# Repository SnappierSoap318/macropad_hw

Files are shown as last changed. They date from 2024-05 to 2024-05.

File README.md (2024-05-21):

# macropad_hw
Hardware for macropad

# Bom
|#  |Reference |Qty|Value |Footprint |DNP|
|---|---|---|---|---|---|
|1  |BT1 |1  |Battery_Cell|Battery:BatteryHolder_MPD_BH-18650-PC2 | |
|2  |C1 |1  |1uF |Capacitor_THT:C_Disc_D4.3mm_W1.9mm_P5.00mm | |
|3  |C2 |1  |0.1uF |Capacitor_THT:C_Disc_D4.3mm_W1.9mm_P5.00mm | |
|4  |D1, D2, D3, D4, D5, D6, D7, D8, D9, D10, D11, D12, D13, D14, D15, D16 |16 |LED |Diode_SMD:D_1206_3216Metric | |
|5  |H1, H2, H3, H4, H5, H6, H7, H8 |8  |MountingHole|MountingHole:MountingHole_2.5mm | |
|6  |SW1 |1  |SW_SPST |Button_Switch_THT:SW_CuK_JS202011CQN_DPDT_Straight| |
|7  |U1 |1  |CD74HC4067M |Package_SO:SOIC-24W_7.5x15.4mm_P1.27mm | |
|8  |U2, U3, U4, U5, U6, U7, U8, U9, U10, U11, U12, U13, U14, U15, U16, U17|16 |~ |Gateron:Gatreon KS-20 | |
|9  |U18 |1  |~ |Nice!nano | |

this is aimed a wireless Analog macropad, any suggestions and changes are welcome.

PS, ik there isnt any holes to move the switches, have to add that in the next revision of the dxf files maybe.

PS:2, The code for running this is [here](https://github.com/SnappierSoap318/macropad)

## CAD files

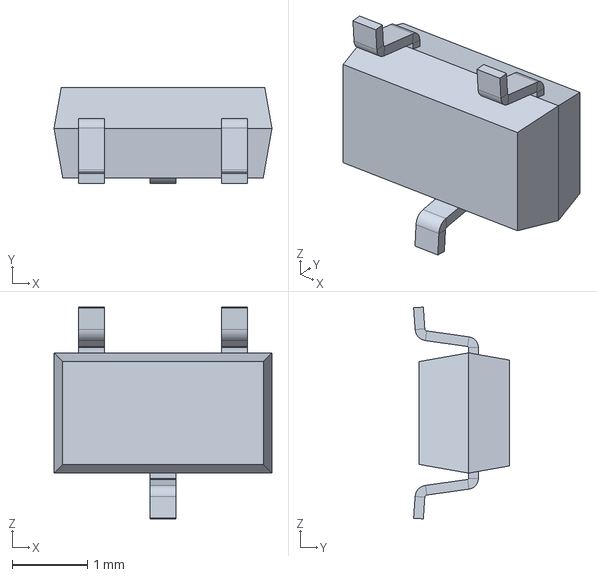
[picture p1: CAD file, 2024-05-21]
3d/sps-siot-magnetic-sensor-ic-cad-rendering-sot-23-ciid-150231.stp
2.90 x 1.27 x 2.82 mm

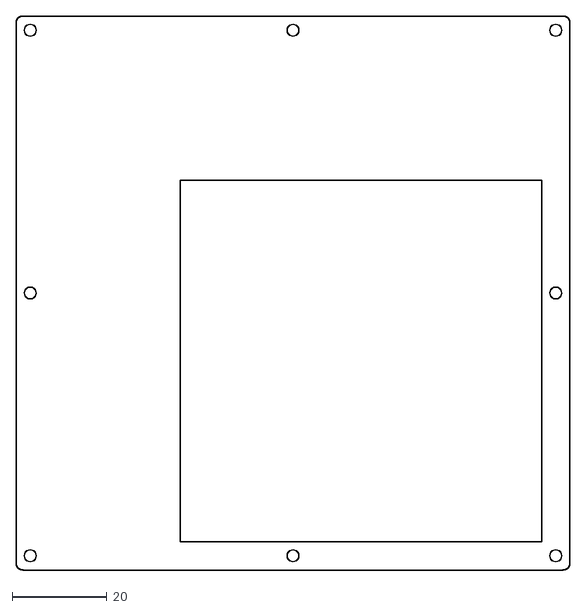
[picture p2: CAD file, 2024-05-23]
Laser Cut/top.dxf
116.8 x 116.8

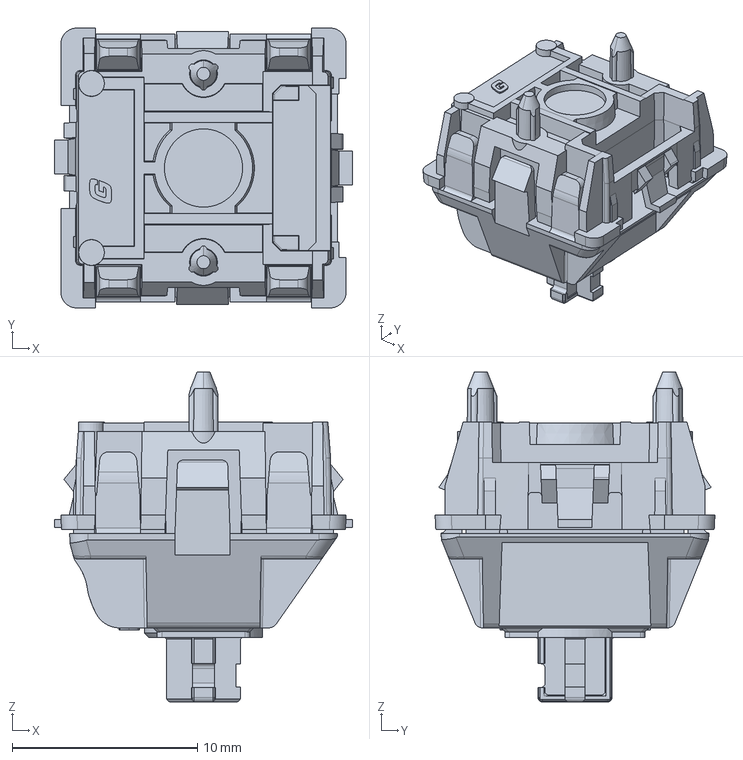
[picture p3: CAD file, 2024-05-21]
3d/Gateron KS-20 Magnetic Hall Sensor Switch KS-20T-20210922.stp
16.1 x 15.1 x 17.8 mm

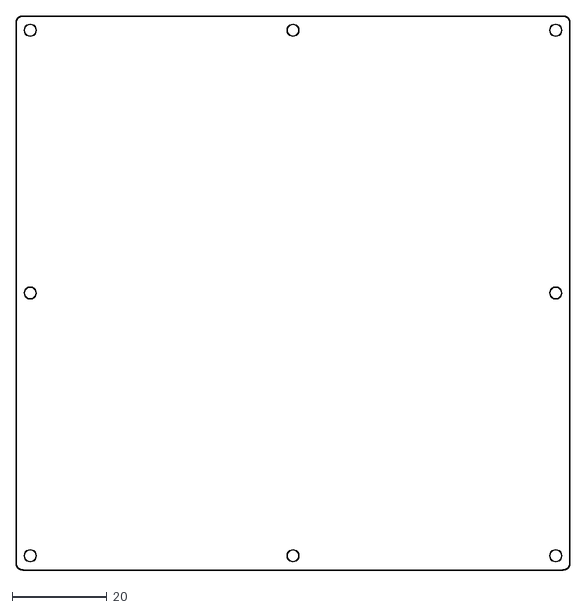
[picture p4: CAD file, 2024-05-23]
Laser Cut/bottom.dxf
116.8 x 116.8

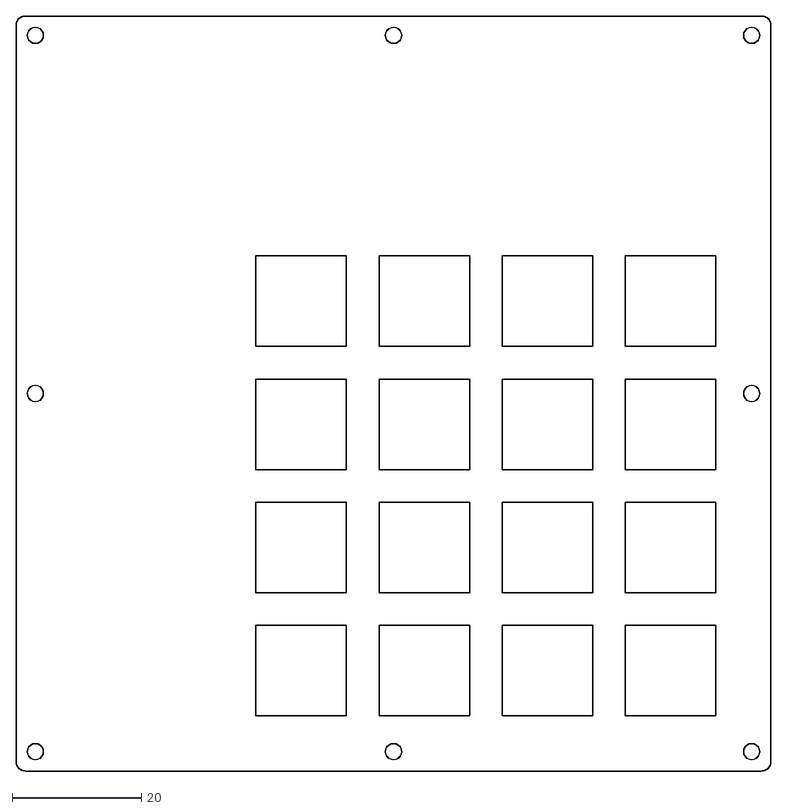
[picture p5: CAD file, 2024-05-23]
Laser Cut/switch.dxf
116.8 x 116.8

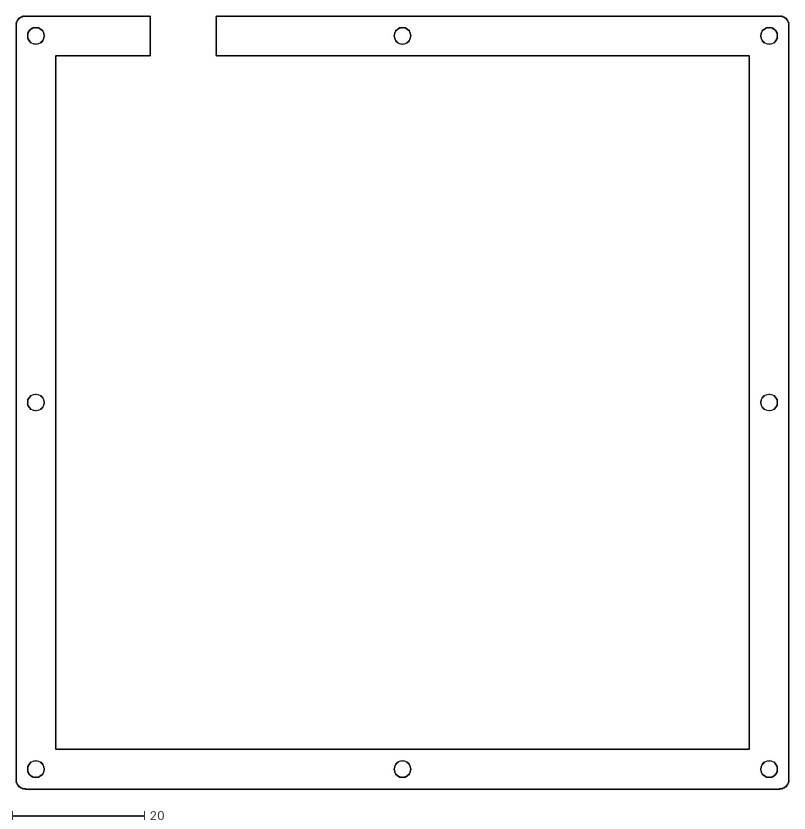
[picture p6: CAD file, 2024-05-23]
Laser Cut/open.dxf
116.8 x 116.8

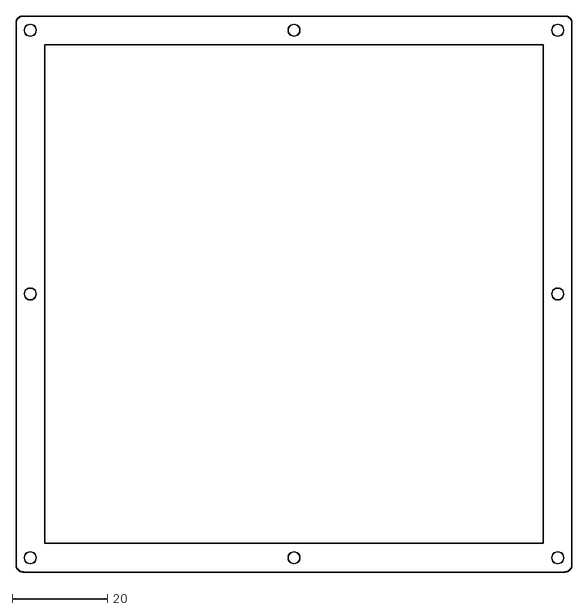
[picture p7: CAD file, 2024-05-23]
Laser Cut/closed.dxf
116.8 x 116.8

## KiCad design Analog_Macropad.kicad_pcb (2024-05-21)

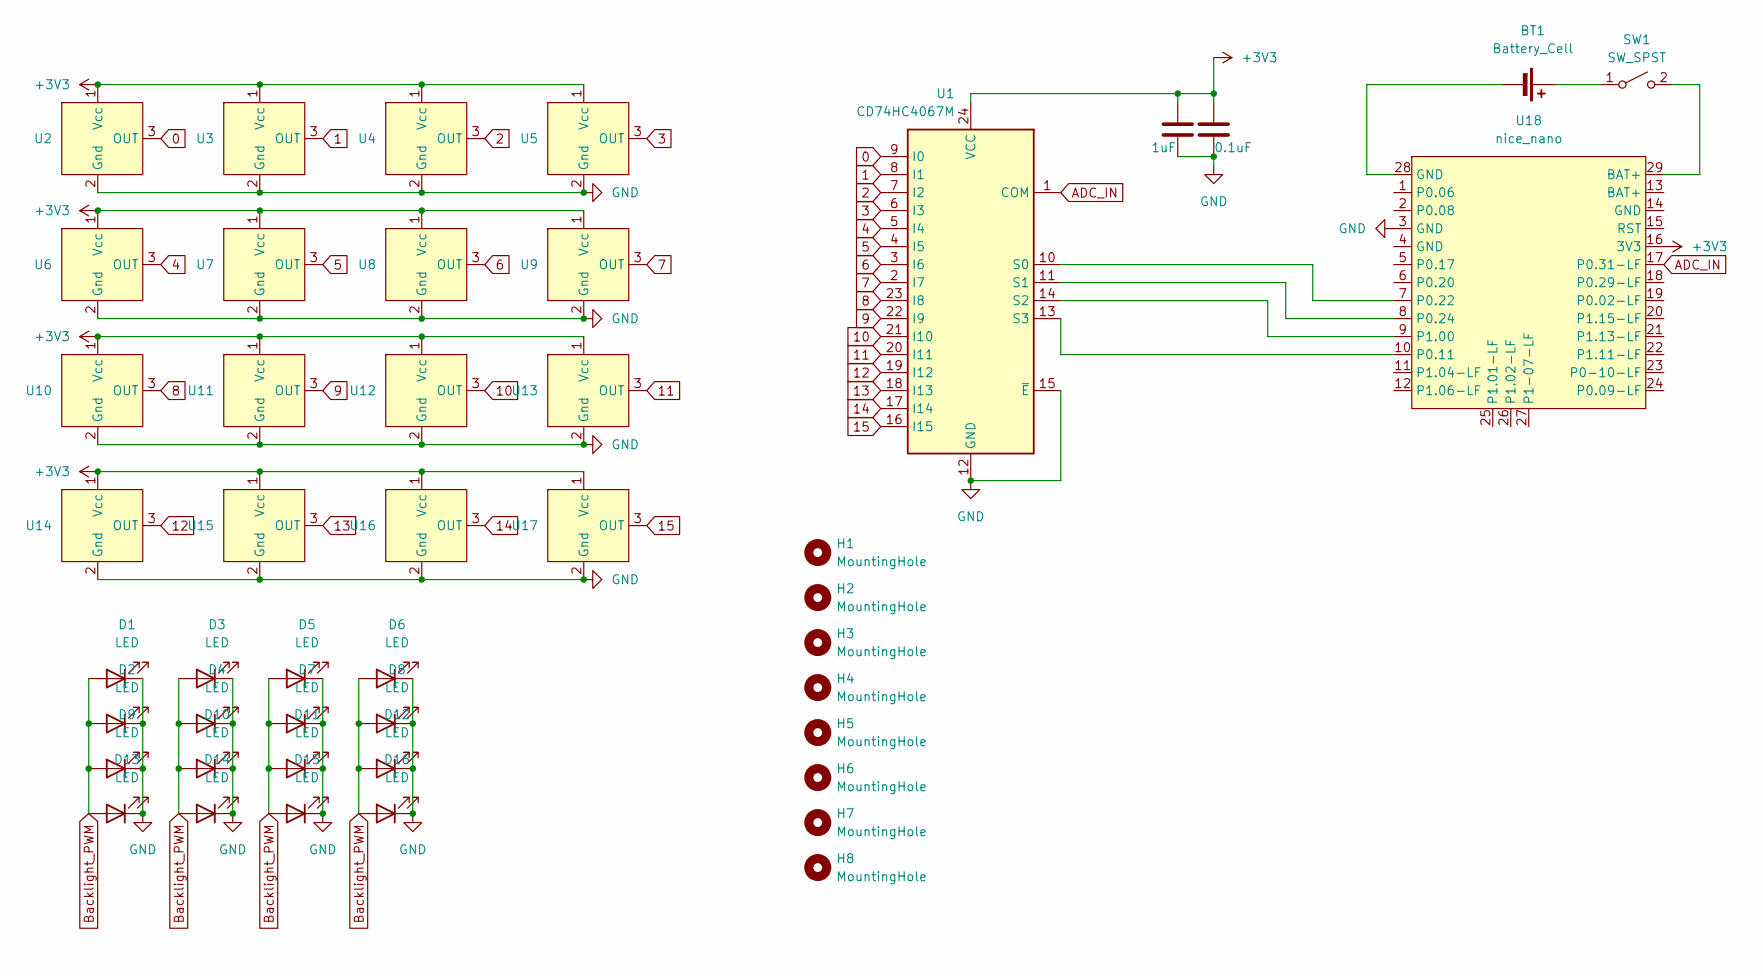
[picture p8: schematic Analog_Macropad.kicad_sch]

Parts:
BT1: Battery_Cell; BatteryHolder_MPD_BH-18650-PC2
C3: 1uF; C_Disc_D4.3mm_W1.9mm_P5.00mm
C4: 0.1uF; C_Disc_D4.3mm_W1.9mm_P5.00mm
D1, D2, D3, D4, D5, D6, D7, D8, D9, D10, D11, D12, D13, D14, D15, D16: LED; D_1206_3216Metric
H1, H2, H3, H4, H5, H6, H7, H8: MountingHole; MountingHole_2.5mm
SW1: SW_SPST; SW_CuK_JS202011CQN_DPDT_Straight
U1: CD74HC4067M; SOIC-24W_7.5x15.4mm_P1.27mm
U2, U3, U4, U5, U6, U7, U8, U9, U10, U11, U12, U13, U14, U15, U16, U17: Gatreon KS-20
U18: nice_nano; nice_nano_AH_USBup

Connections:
0: U1.9 (I0), U2.3 (OUT)
1: U1.8 (I1), U3.3 (OUT)
2: U1.7 (I2), U4.3 (OUT)
3: U1.6 (I3), U5.3 (OUT)
4: U1.5 (I4), U6.3 (OUT)
5: U1.4 (I5), U7.3 (OUT)
6: U1.3 (I6), U8.3 (OUT)
7: U1.2 (I7), U9.3 (OUT)
8: U1.23 (I8), U10.3 (OUT)
9: U1.22 (I9), U11.3 (OUT)
10: U1.21 (I10), U12.3 (OUT)
11: U1.20 (I11), U13.3 (OUT)
12: U1.19 (I12), U14.3 (OUT)
13: U1.18 (I13), U15.3 (OUT)
14: U1.17 (I14), U16.3 (OUT)
15: U1.16 (I15), U17.3 (OUT)
+3V3: U1.24 (VCC), U2.1 (Vcc), U3.1 (Vcc), U4.1 (Vcc), U5.1 (Vcc), U6.1 (Vcc), U7.1 (Vcc), U8.1 (Vcc), U9.1 (Vcc), U10.1 (Vcc), U11.1 (Vcc), U12.1 (Vcc), U13.1 (Vcc), U14.1 (Vcc), U15.1 (Vcc), U16.1 (Vcc), U17.1 (Vcc), U18.16 (3V3); also elsewhere on the board
ADC_IN: U1.1 (COM), U18.17 (P0.31-LF)
Backlight_PWM: D1.2 (A), D2.2 (A), D3.2 (A), D4.2 (A), D5.2 (A), D6.2 (A), D7.2 (A), D8.2 (A), D9.2 (A), D10.2 (A), D11.2 (A), D12.2 (A), D13.2 (A), D14.2 (A), D15.2 (A), D16.2 (A)
GND: D1.1 (K), D2.1 (K), D3.1 (K), D4.1 (K), D5.1 (K), D6.1 (K), D7.1 (K), D8.1 (K), D9.1 (K), D10.1 (K), D11.1 (K), D12.1 (K), D13.1 (K), D14.1 (K), D15.1 (K), D16.1 (K), U1.12 (GND), U1.15 (~E), U2.2 (Gnd), U3.2 (Gnd), U4.2 (Gnd), U5.2 (Gnd), U6.2 (Gnd), U7.2 (Gnd), U8.2 (Gnd), U9.2 (Gnd), U10.2 (Gnd), U11.2 (Gnd), U12.2 (Gnd), U13.2 (Gnd), U14.2 (Gnd), U15.2 (Gnd), U16.2 (Gnd), U17.2 (Gnd), U18.3 (GND); also elsewhere on the board
unnamed: BT1.1 (+), SW1.1 (A)
unnamed: BT1.2 (-), U18.28 (GND)
unnamed: SW1.2 (B), U18.29 (BAT+)
unnamed: U1.10 (S0), U18.7 (P0.22)
unnamed: U1.11 (S1), U18.8 (P0.24)
unnamed: U1.14 (S2), U18.9 (P1.00)
unnamed: U1.13 (S3), U18.10 (P0.11)

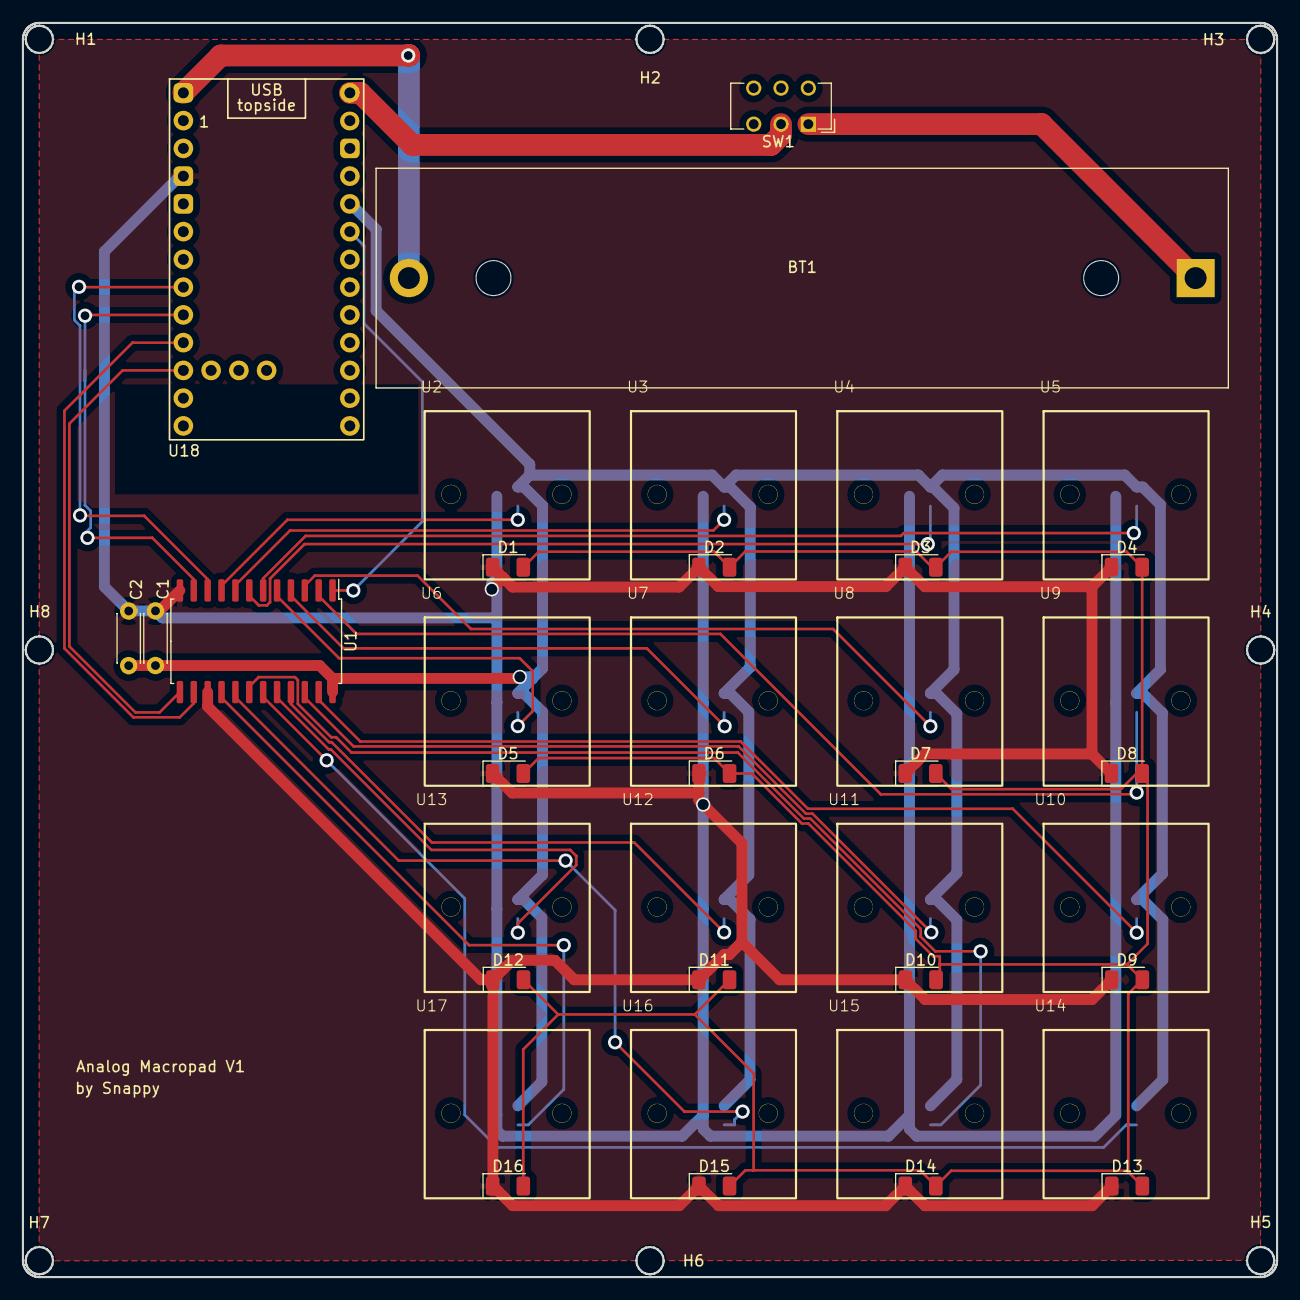
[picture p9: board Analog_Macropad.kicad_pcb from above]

Board: 2 copper layers, 114.8 x 114.8 mm, 46 parts (0 on the bottom side), 27 nets.

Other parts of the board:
C1: 1uF; C_Disc_D4.3mm_W1.9mm_P5.00mm
C2: 0.1uF; C_Disc_D4.3mm_W1.9mm_P5.00mm

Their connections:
+3V3: C1.2, C2.1; also elsewhere on the board
GND: C1.1, C2.2; also elsewhere on the board

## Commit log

2024-05-21 Add Laser cut files
    [bottom.dxf, closed.dxf, open.dxf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]
2024-05-21 Added Schematic, PCB layout and custom footprint
    [Analog_Macropad.kicad_pcb, Analog_Macropad.kicad_sch]
2024-05-21 Added Gerber files
    [Analog_Macropad-B_Cu.gbr, Analog_Macropad-B_Mask.gbr, Analog_Macropad-B_Paste.gbr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]
2024-05-21 add 3d files
    [Gateron KS-20 Magnetic Hall Sensor Switch KS-20T-20210922.stp, sps-siot-magnetic-sensor-ic-cad-rendering-sot-23-ciid-150231.stp]
2024-05-23 update laser cut files to fix dimensions
    [bottom.dxf, closed.dxf, open.dxf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]
